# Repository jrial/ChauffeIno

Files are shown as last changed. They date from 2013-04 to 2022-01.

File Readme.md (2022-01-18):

ChauffeIno
==========

**Superseded by HA configuration. This project is incomplete and no longer maintained.**

Intelligently control the central heating unit (burner, solenoid valves) via wireless thermostats based on [Moteino](http://lowpowerlab.com/moteino/)s (Small low-power radio-enabled Arduino clones) and a [Raspberry Pi](http://www.raspberrypi.org/).

Arduino library requirements:
-----------------------------
* [avr](http://playground.arduino.cc/Main/AVR): comes with avr-libc, required package for arduino-core
* [LiquidCrystal](http://arduino.cc/en/Tutorial/LiquidCrystal): part of the arduino-core package
* [OneWire](http://www.pjrc.com/teensy/td_libs_OneWire.html)
* [RFM12B](https://github.com/LowPowerLab/RFM12B)
* [Dallas Temperature Control Library](http://milesburton.com/Dallas_Temperature_Control_Library)

Arduino hardware requirements:
------------------------------
* [Hitachi HD44780 compatible LCD](http://lcd-linux.sourceforge.net/pdfdocs/hd44780.pdf)
* [Dallas Semiconducor DS18x20](http://datasheets.maximintegrated.com/en/ds/DS18B20.pdf)

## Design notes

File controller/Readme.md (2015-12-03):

Chauffeino Controller
=====================

The Short
---------
The controller is a BeagleBone Black unit, receiving sensor data through the receiver (Moteino). It holds the programming, per room warm-up data and all the temperature logs from the various sensor nodes. It uses this data to decide when to activate the heating circuits and whether to turn the burner on or off.

Configuration happens via a web interface, with possible future expansions including mobile apps.

After receiving data from a thermostat node through the receiver, the controller can send back data such as "you are in zone Living Room, program sequence 17; your temperature demand is 22&deg;C, which overrides the programmed temperature upwards and the valve for your room is open", which the thermostat node can then use to update the values on its LCD. See the README file in /thermostat for more info.

Design Questions
----------------
Need to investigate whether the premise that keeping water at a certain temperature T by turning the burner on when the temperature drops to T-d degrees consumes the same amount of fuel as allowing the temperature to drop to a lower value B, if under the first schedule the burner is turned on n times where T-B = n*d. Or to put this in numbers: do we consume the same amount of fuel when we try to keep the water at 80&deg;C if we have to turn the burner on 12 times during the day whenever the temperature drops to 75, as opposed to letting the water cool down to 20&deg;C and warm it up again to 80&deg;C? If that's the case, the burner can be switched off whenever there's no heat demand, as long as it's turned on again in time for the water to reach its set temperature by the time the next heat demand occurs.

Basic security needs to be built in: when sensor nodes fail to report for prolonged periods of time, the heat flow to those rooms should be disabled, or possibly throttled based on heuristics: I'm thinking room warm-up and cooldown speed data, taking outside temperature into account. Warnings need to be sent to the user (email, sms, ...?) so they can take appropriate action.

Connecting the SainSmart 16-channel Relay Board
-----------------------------------------------

The SainSmart 16-channel Relay Board needs 12V  + Ground on the 12V terminal connector, a +5V input on the 5V pin. The rest of the pins need to be pulled low in order to activate the corresponding relay. Alternatively, you can put ground on the GND pin, and pull the relay pins low. Either way, the relay pins need to be pulled low to activate the relay.

The relays are toggle switches; when they're active (LED on), the middle pin is connected to the left one. When they're inactive (LED off), the middle pin is connected to the right pin.

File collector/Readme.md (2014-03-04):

Chauffeino Collector
====================

The Short
---------
The collector is a Moteino connected to the controller (BeagleBone Black). Its task is to listen to incoming sensor reports and pass them along to the BBB. Its secondary function is to collect sensor data from the external temperature sensor, which is passed along to the BBB in the same fashion as the rest of the sensor logs.

Whenever it receives sensor data from a node, it will pass this data to the BBB and listen on the serial interface for the BBB's response. If one arrives, it's sent to the node in question. For this to work, the thermostat will remain listening for a short while after sending its data.

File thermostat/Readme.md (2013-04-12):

Chauffeino Thermostat
=====================

The short
---------
The thermostat is a simple [Moteino](http://lowpowerlab.com/moteino/) unit with an LCD and two push-buttons. The LCD displays the room name and the current and requested temperature. The push buttons can be used to override the programming to demand more or less heat.

How it works
------------
The thermostat gathers temperature readings from a Dallas Semiconductor [DS18B20](http://datasheets.maximintegrated.com/en/ds/DS18B20.pdf), buffers them, and sends them to the collector on a regular interval. The collector then passes that data along to the controller. The thermostat can receive a response from the controller through the collector, which it can use to update the values on its LCD. The unit will be sleeping between measurements, but can be woken from the sleep state when one of the push buttons is pressed. It will wait for 3 seconds after the last keypress, after which it will send the "requested temperature set to X&deg;C" event to the controller. Overridden temperatures are valid until the next programming sequence.

Design Questions
----------------
Timing is something that needs to be determined. One approach is to have every node check in once every minute or every two minutes, and remain dormant for most of its time. Another approach is to collect data, but only check in when the temperature deviates more than 0.5&deg;C from its last reported value in order to save battery, and at least once every 5 or 10 minutes so that the controller knows the sensor is still alive. And perhaps every minute whenever the burner on event is received so the controller can build a high-res warm-up curve for the room in question.

Display example, upon receiving the response "you are in zone Living Room, program sequence 17; your temperature demand is 22&deg;C, which overrides the programmed temperature upwards and the valve for your room is open", it might display something like:

    20.3/22.0 C      ^
    Living Room      *

This is interpreted as:

* 20.3&deg;C current temperature
* 22.0&deg;C requested
* Programming temporarily overridden upwards (^)
* Zone called "Living Room"
* Burner on (*)

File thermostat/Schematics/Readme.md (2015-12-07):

Schematics
==========

The schematics in this folder are created with Fritzing. For some reason, the autorouting doesn't pick up all connections made on the breadboard view. Possibly due to errors in the parts definitions, I have no idea.

Will update with proper schematics and board files later. For now it's sufficient to document my breadboard layout so this thing can be duplicated.

The final version may not even use a Moteino, but straight Atmel Agmega328P chips with the supporting passive parts and a RFM69 breakout boards from eBay of AliExpress.

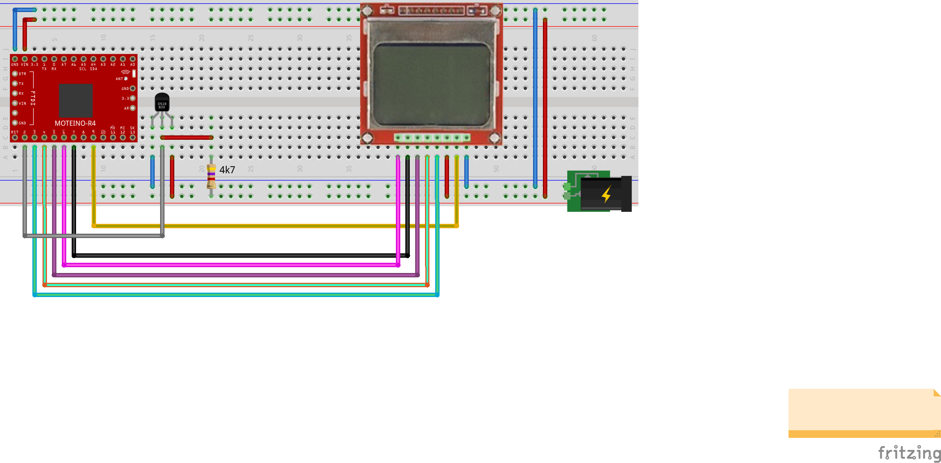
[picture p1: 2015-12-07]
thermostat/Schematics/Chauffeino_Thermomstat_bb.png

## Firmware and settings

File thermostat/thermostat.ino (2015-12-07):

/*
This sketch turns the moteino into a thermostat node. It reads the temperature
from a Dallas Semiconductor TS18B20 temerature sensor over the One-Wire
protocol. It uses an LCD to display status info, and two buttons to override
the programmed temperature. The program is not kept on the device, it is
stored on the controller unit, and info on the currently active program
is transmitted back to the thermostat.
*/

/*
TODO:
* Wireless reporting
* Wireless feedback from controller
* Override buttons
*/

#include <OneWire.h>
#include <DallasTemperature.h>
#include <RFM69.h>
#include <avr/sleep.h>
#include <LowPower.h>
#include <SPI.h>
//#include <ChauffeinoDisplay.h>

// Global vars - generic
uint8_t tempUpPin = 4;
uint8_t tempDownPin = 5;
const uint8_t bufferSize = 3;
uint8_t bufferPos = 0;
float buffer[bufferSize];
float heatDemand = 16.0;
#define SERIAL_BAUD  115200

// RFM69
// #define BOOT_NODEID 127  //network ID used for this unit at boot time
#define NETWORKID   98  //the network ID we are on
#define GATEWAYID   1  //the node ID we're sending to
#define ACK_TIME    50  // # of ms to wait for an ack
#define FREQUENCY   RF69_433MHZ
#define NODEID      10
// uint8_t nodeid;
const char KEY[] = "SOMERANDOMSTRING";
RFM69 radio;
bool requestACK=true;

// Battery related
int8_t batt_counter=-1;
bool low_batt = false;
uint16_t min_vcc = 2750;
const long scaleConst = 1156.300 * 1000 ; // internalRef * 1023 * 1000;

// DS18x20
int sensorPin = 3;
OneWire oneWire(sensorPin);
DallasTemperature sensors(&oneWire);
DeviceAddress sensor;
char sensorString[8];

// LCD
// uint8_t lcdPins[] = {14, 15, 16, 17, 18, 19};
// ChauffeinoDisplay display(lcdPins);

typedef struct {
    int           nodeId;   // ID of the node (later this will be autodiscovered; for now hardcoded)
    char          sensorId[16]; // ID of the sensor; this is the node's ID card on the netwwork
    float         temp;     // Temperature
} Payload;
Payload reportData;


void setup()
{
    // Setup serial line for debugging
    Serial.begin(SERIAL_BAUD);
    Serial.println("Thermostat initialising");
    radio.initialize(FREQUENCY,NODEID,NETWORKID);
    radio.encrypt(KEY);
    char buff[50];
    sprintf(buff, "\nTransmitting at %d Mhz...", FREQUENCY==RF69_433MHZ ? 433 : FREQUENCY==RF69_868MHZ ? 868 : 915);
    Serial.println(buff);
    sprintf(buff, "Encryption key: %s", KEY);
    Serial.println(buff);
    radio.sleep();
    // Setup LCD
    // display.setDimensions(2, 16);
    // display.print("Chauffeino", 0, 0);
    // Setup thermal sensor
    pinMode(sensorPin, INPUT);
    sensors.begin();
    if (sensors.getDeviceCount()) {
        sensors.getAddress(sensor, 0);
        char sensorString[16];
        char tmp_hex[2];
        for (uint8_t i = 0; i < 8; i++) {
            sprintf(tmp_hex, "%02x", sensor[i]);
            sensorString[i*2] = tmp_hex[0];
            sensorString[i*2+1] = tmp_hex[1];
            // sensorString[i*2] =  sensor[i];
        }
        sprintf(buff, "Sensor ID: %s", sensorString);
        Serial.println(buff);
        if (sensor[0] == DS18B20MODEL || sensor[0] == DS1825MODEL || sensor[0] == DS1822MODEL)
            sensors.setResolution(sensor, 12);
        else if (sensor[0] == DS18S20MODEL)
            sensors.setResolution(sensor, 9);
        else {
            Serial.println("Sensors found, but not Dallas DS18x20 family.\nTerminating.");
            // display.print("SENSOR ERROR!!!", 1, 0);
            flushSerial();
            LowPower.powerDown(SLEEP_FOREVER, ADC_OFF, BOD_OFF);
        }
        int resolution = sensors.getResolution(sensor);
        sprintf(buff, "Sensor resolution: %d", resolution);
        Serial.println(buff);
        // display.print(buff, 1, 0);
        // With that done, let's get ourselves a node ID, shall we?
        /*
        radio.Initialize(BOOT_NODEID, FREQUENCY, NETWORKID);
        radio.Encrypt(KEY);
        String msg = "request_node_id ";
        msg += sensor_string;
        radio.Send(GATEWAYID, &msg, msg.length());
        */
        reportData.nodeId = NODEID;
        for (uint8_t i = 0; i<16; i++) {
            reportData.sensorId[i] = sensorString[i];
        }
    } else {
        Serial.println("No sensors found.\nTerminating.");
        // display.print("SENSOR ERROR!!!", 1, 0);
        flushSerial();
        LowPower.powerDown(SLEEP_FOREVER, ADC_OFF, BOD_OFF);
    }
    Serial.println("Thermostat initialisation complete.");
}


void loop()
{
    // Check battery level every hour
    batt_counter = (batt_counter + 1) % 60;
    // Resetting Low Battery warning should require a reset or restart
    if (! low_batt && batt_counter == 0) {
        if (readVccMv() < min_vcc) {
            low_batt = true;
        }
    }
    // Get temperature in °C
    Serial.println("Requesting temperature");
    sensors.requestTemperaturesByAddress(sensor);
    float tempC = sensors.getTempC(sensor);
    // Update display
    // display.setId(room);
    // display.setTemperatures(tempC, heatDemand);
    // display.clear();
    // display.printTemperatures(low_batt);
    // display.printId();
    Serial.print("Temperature: ");
    Serial.println(tempC);
    // and store it in the output buffer at position bufferPos.
    buffer[bufferPos] = tempC;
    // rotate to next position in output buffer.
    bufferPos = (bufferPos + 1) % bufferSize;
    reportData.temp = tempC;
    if (radio.sendWithRetry(GATEWAYID, (const void*)(&reportData), sizeof(reportData)))
      Serial.print(" ok!");
    else Serial.print(" nothing...");
    Serial.println();
    // If buffer full, report wirelessly and clear buffer
    if (not bufferPos) {
        // TODO: report *wirelessly*
        for (int i = 0; i < bufferSize; i++) {
            Serial.print("Temp ");
            Serial.print(i);
            Serial.print(": ");
            Serial.println(buffer[i]);
        }
        // TODO: listen for commands from controller
    }
    // Sleep for a minute
    flushSerial();
    // for (int i=0; i<6; i++) {
    //     LowPower.powerDown(SLEEP_8S, ADC_OFF, BOD_OFF);
    //     LowPower.powerDown(SLEEP_2S, ADC_OFF, BOD_OFF);
    // }
    LowPower.powerDown(SLEEP_2S, ADC_OFF, BOD_OFF);
}

// Helper method to properly flush; HardwareSerial::flush() seems broken
// See http://forum.arduino.cc/index.php?topic=151014.0, esp. this post:
// http://forum.arduino.cc/index.php?topic=151014.msg1344132#msg1344132
void flushSerial() {
    while (!(UCSR0A & (1 << UDRE0)))  // Wait for empty transmit buffer
    UCSR0A |= 1 << TXC0;  // mark transmission not complete
    while (!(UCSR0A & (1 << TXC0)));   // Wait for the transmission to complete
}

/*
  Check battery level; return external voltage,
  calculated against high-precision 1.1V internal
  VREF.
  Taken from http://code.google.com/p/tinkerit/wiki/SecretVoltmeter
  */
// long readVccMv() {
//     long result;
//     // Read 1.1V reference against AVcc
//     ADMUX = _BV(REFS0) | _BV(MUX3) | _BV(MUX2) | _BV(MUX1);
//     delay(2); // Wait for Vref to settle
//     ADCSRA |= _BV(ADSC); // Convert
//     while (bit_is_set(ADCSRA,ADSC));
//     result = ADCL;
//     result |= ADCH<<8;
//     result =  1126400L / result; // Back-calculate AVcc in mV
//     return (uint16_t) result;
// }

// Better ReadVcc method.
// Taken from http://www.rcgroups.com/forums/showthread.php?t=1874973
int readVccMv() {
    // Read 1.1V reference against AVcc
    // set the reference to Vcc and the measurement to the internal 1.1V reference
// Leonardo, Micro, Esplora, Duemilanove, Mega 2560, Mega ADK
#if defined(__AVR_ATmega32U4__) || defined(__AVR_ATmega1280__) || defined(__AVR_ATmega2560__)
    ADMUX = _BV(REFS0) | _BV(MUX4) | _BV(MUX3) | _BV(MUX2) | _BV(MUX1);
// No clue, not planning to look it up
#elif defined (__AVR_ATtiny24__) || defined(__AVR_ATtiny44__) || defined(__AVR_ATtiny84__)
    ADMUX = _BV(MUX5) | _BV(MUX0);
// No clue, not planning to look it up
#elif defined (__AVR_ATtiny25__) || defined(__AVR_ATtiny45__) || defined(__AVR_ATtiny85__)
    ADMUX = _BV(MUX3) | _BV(MUX2);
// All others
#else
    ADMUX = _BV(REFS0) | _BV(MUX3) | _BV(MUX2) | _BV(MUX1);
#endif

  delay(2); // Wait for Vref to settle
  ADCSRA |= _BV(ADSC); // Start conversion
  while (bit_is_set(ADCSRA,ADSC)); // measuring

  uint8_t low  = ADCL; // must read ADCL first - it then locks ADCH
  uint8_t high = ADCH; // unlocks both

  long result = (high<<8) | low;

  //result = 1125300L / result; // Calculate Vcc (in mV); 1125300 = 1.1*1023*1000
  result = scaleConst / result; // Calculate Vcc (in mV); 1125300 = 1.1*1023*1000
  return (int)result; // Vcc in millivolts
}

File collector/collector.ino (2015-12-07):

#include <RFM69.h>
#include <SPI.h>

#define NODEID      1
#define NETWORKID   98
#define FREQUENCY   RF69_433MHZ //Match this with the version of your Moteino! (others: RF69_433MHZ, RF69_868MHZ)
#define KEY         "SOMERANDOMSTRING" //has to be same 16 characters/bytes on all nodes, not more not less!
#define LED         9
#define SERIAL_BAUD 115200
#define ACK_TIME    30  // # of ms to wait for an ack

RFM69 radio;
bool promiscuousMode = false; //set to 'true' to sniff all packets on the same network

typedef struct {
    int           nodeId; //store this nodeId
    char          sensorId[16]; // ID of the sensor; this is the node's ID card on the netwwork
    float         temp;   //temperature maybe?
} Payload;
Payload theData;

void setup() {
    Serial.begin(SERIAL_BAUD);
    delay(10);
    radio.initialize(FREQUENCY,NODEID,NETWORKID);
    //radio.setHighPower(); //uncomment only for RFM69HW!
    radio.encrypt(KEY);
    radio.promiscuous(promiscuousMode);
    char buff[50];
    sprintf(buff, "\nListening at %d Mhz...", FREQUENCY==RF69_433MHZ ? 433 : FREQUENCY==RF69_868MHZ ? 868 : 915);
    Serial.println(buff);
}

byte ackCount=0;
void loop() {
    if (radio.receiveDone()) {
        Serial.print('[');Serial.print(radio.SENDERID, DEC);Serial.print("] ");
        Serial.print(" [RX_RSSI:");Serial.print(radio.readRSSI());Serial.print("]");
        if (promiscuousMode) {
            Serial.print("to [");Serial.print(radio.TARGETID, DEC);Serial.print("] ");
        }

        if (radio.DATALEN != sizeof(Payload))
        Serial.print("Invalid payload received, not matching Payload struct!");
        else {
            theData = *(Payload*)radio.DATA; //assume radio.DATA actually contains our struct and not something else
            Serial.print(" nodeId=");
            Serial.print(theData.nodeId);
            Serial.print(" sensorId=");
            Serial.print(theData.sensorId);
            Serial.print(" temp=");
            Serial.print(theData.temp);
        }

        if (radio.ACKRequested()) {
            byte theNodeID = radio.SENDERID;
            radio.sendACK();
            Serial.print(" - ACK sent.");

            // When a node requests an ACK, respond to the ACK
            // and also send a packet requesting an ACK (every 3rd one only)
            // This way both TX/RX NODE functions are tested on 1 end at the GATEWAY
            // if (ackCount++%3==0) {
            //     Serial.print(" Pinging node ");
            //     Serial.print(theNodeID);
            //     Serial.print(" - ACK...");
            //     delay(3); //need this when sending right after reception .. ?
            //     if (radio.sendWithRetry(theNodeID, "ACK TEST", 8, 0))  // 0 = only 1 attempt, no retries
            //         Serial.print("ok!");
            //     else
            //         Serial.print("nothing");
            // }
        }
        Serial.println();
        Blink(LED,3);
    }
}



void Blink(byte PIN, int DELAY_MS)
{
    pinMode(PIN, OUTPUT);
    digitalWrite(PIN,HIGH);
    delay(DELAY_MS);
    digitalWrite(PIN,LOW);
}

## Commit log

2013-04-11 Initial commit: basic temperature collection, LCD output, serial debug info
2014-02-28 Adding Low-Power library
2014-02-28 [FIX] Typo in DS18* model prevented sketch from running
    [thermostat.ino]
2014-02-28 Be Low power mode instead of dumb sleep, also power down radio when not in use
2014-02-28 Properly go in low power mode when no sensor found
2014-03-03 Added battery monitor
2014-03-03 FIXME should be TODO
    [thermostat.ino]
2014-03-03 [FIX] Dump HardwareSerial::flush() in favor of non-broken solution
    [thermostat.ino]
2014-03-04 Change reference to Raspberry Pi to BeagleBone Black
2015-12-03 Added notes on the SainSmart 16-channel relay board
2015-12-07 Add schematics for thermostat
    [Chauffeino_Thermomstat.fzz]
2015-12-07 Switch thermostat to RFM69, add transmission; use 2s update interval for testing
